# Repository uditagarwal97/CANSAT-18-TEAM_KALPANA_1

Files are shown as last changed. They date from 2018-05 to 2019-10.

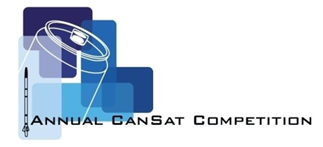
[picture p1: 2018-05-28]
GCS_VIEW/images/acc.PNG

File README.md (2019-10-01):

View this project on [CADLAB.io](https://cadlab.io/project/1174). 

# CANSAT-18-TEAM_KALPANA_1
This Repository contains all the code developed during CANSAT'18 compitition by Team Kalpana-1(ID 2426).

## About the CanSat compition
This annual competition is open to teams from universities and colleges. Teams were asked to design and build a space-type system, following the approved competition guide, and then compete against each at the end of two semesters to determine the winners. For more information please head over to: 
[Compitition website](http://www.cansatcompetition.com/index.html)

## Our problem statement
The 2018 mission simulates a space probe (CanSat) entering a planetary atmosphere. The probe shall carry a single large hen's egg. The egg must survive all portions of flight. The operation sequence shall be:

1. The probe is launched to an altitude of 670 meters to 725 meters and then deployed from the rocket. Orientation of deployment is not controlled and is most definitely violent.

2. Once deployed, the probe shall open an aero-braking heat shield. The descent rate shall be kept at 10 to 30 meters/sec. The aero-braking probe must maintain a stable orientation with the heat shield facing the direction of descent during descent. Tumbling is not allowed. Active control surfaces or other non pyrotechnic mechanisms can be used to maintain orientation.

3. At an altitude of 300 meters, the probe shall release the aero-braking heat shield and simultaneously deploy a parachute to reduce the descent rate of 5 meters/sec.

4. The probe shall land leaving the egg intact.

The probe shall include sensors for tracking altitude using air pressure, external temperature, battery voltage and GPS position. A compartment shall be included to hold a large hen's egg. The egg will simulate a delicate instrument. 

Visit the following link for detailed info of our approach: [Link](http://uditagarwal.in/wiki/index.php/CANSAT18)

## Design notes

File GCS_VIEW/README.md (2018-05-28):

# GCSView
This folder contains GUI files developed for Ground Control Station to view incoming data packets in real time. 
Software has been developed in Python using PyQt4 and matplotlib.

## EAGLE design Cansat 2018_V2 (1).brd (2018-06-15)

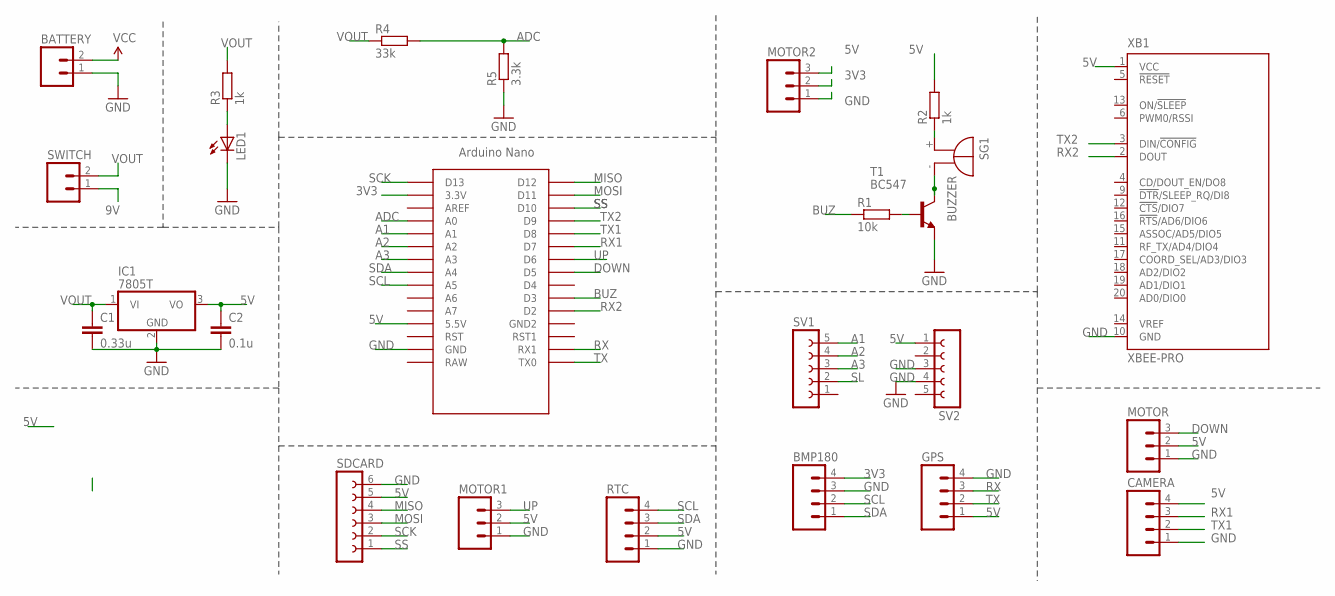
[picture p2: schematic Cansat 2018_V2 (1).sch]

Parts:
BATTERY: M02; 02P
BMP180: M04; 04P
C1: 0.33u; C0805
C2: 0.1u; C0805
CAMERA: M04; 04P
GPS: M04; 04P
IC1: 7805T; TO220H
LED1: LED3MM
MOTOR, MOTOR1, MOTOR2: M03; 03P
R1: 10k; 0207/7
R2: 1k; 0207/7
R3: 1k; 0204/7
R4: 33k; 0207/7
R5: 3.3k; 0207/10
RTC: M04; 04P
SDCARD: FE06-1; FE06
SG1: BUZZER; F/TMB
SV1, SV2: FE05-1
SWITCH: M02; 02P
T1: BC547; TO92
U$1: NANO
XB1: XBEE-PRO

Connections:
3V3: BMP180.4, MOTOR2.2, U$1.3.3V
5V: C2.1, CAMERA.4, GPS.1, IC1.3 (VO), MOTOR.2, MOTOR1.2, MOTOR2.3, R2.2, RTC.2, SDCARD.5, SV2.1, U$1.5V (5.5V), XB1.1 (VCC)
9V: BATTERY.2, SWITCH.1
A1: SV1.5, U$1.A1
A2: SV1.4, U$1.A2
A3: SV1.3, U$1.A3
ADC: R4.2, R5.2, U$1.A0
BUZ: R1.1, U$1.D3
DOWN: MOTOR.3, U$1.D5
GND: BATTERY.1, BMP180.3, C1.2, C2.2, CAMERA.1, GPS.4, IC1.2 (GND), LED1.K (C), MOTOR.1, MOTOR1.1, MOTOR2.1, R5.1, RTC.1, SDCARD.6, SV2.3, SV2.4, T1.1 (E), U$1.GND, XB1.10 (GND)
MISO: SDCARD.4, U$1.D12
MOSI: SDCARD.3, U$1.D11
unnamed: R1.2, T1.2 (B)
unnamed: SG1.-, T1.3 (C)
unnamed: R2.1, SG1.+
unnamed: LED1.A, R3.1
RX: GPS.3, U$1.RX1
RX1: CAMERA.3, U$1.D7
RX2: U$1.D2, XB1.2 (DOUT)
SCK: SDCARD.2, U$1.D13
SCL: BMP180.2, RTC.4, U$1.A5
SDA: BMP180.1, RTC.3, U$1.A4
SL: SV1.2
SS: SDCARD.1, U$1.D10
TX: GPS.2, U$1.TX0
TX1: CAMERA.2, U$1.D8
TX2: U$1.D9, XB1.3 (DIN/!CONFIG)
UP: MOTOR1.3, U$1.D6
VOUT: C1.1, IC1.1 (VI), R3.2, R4.1, SWITCH.2

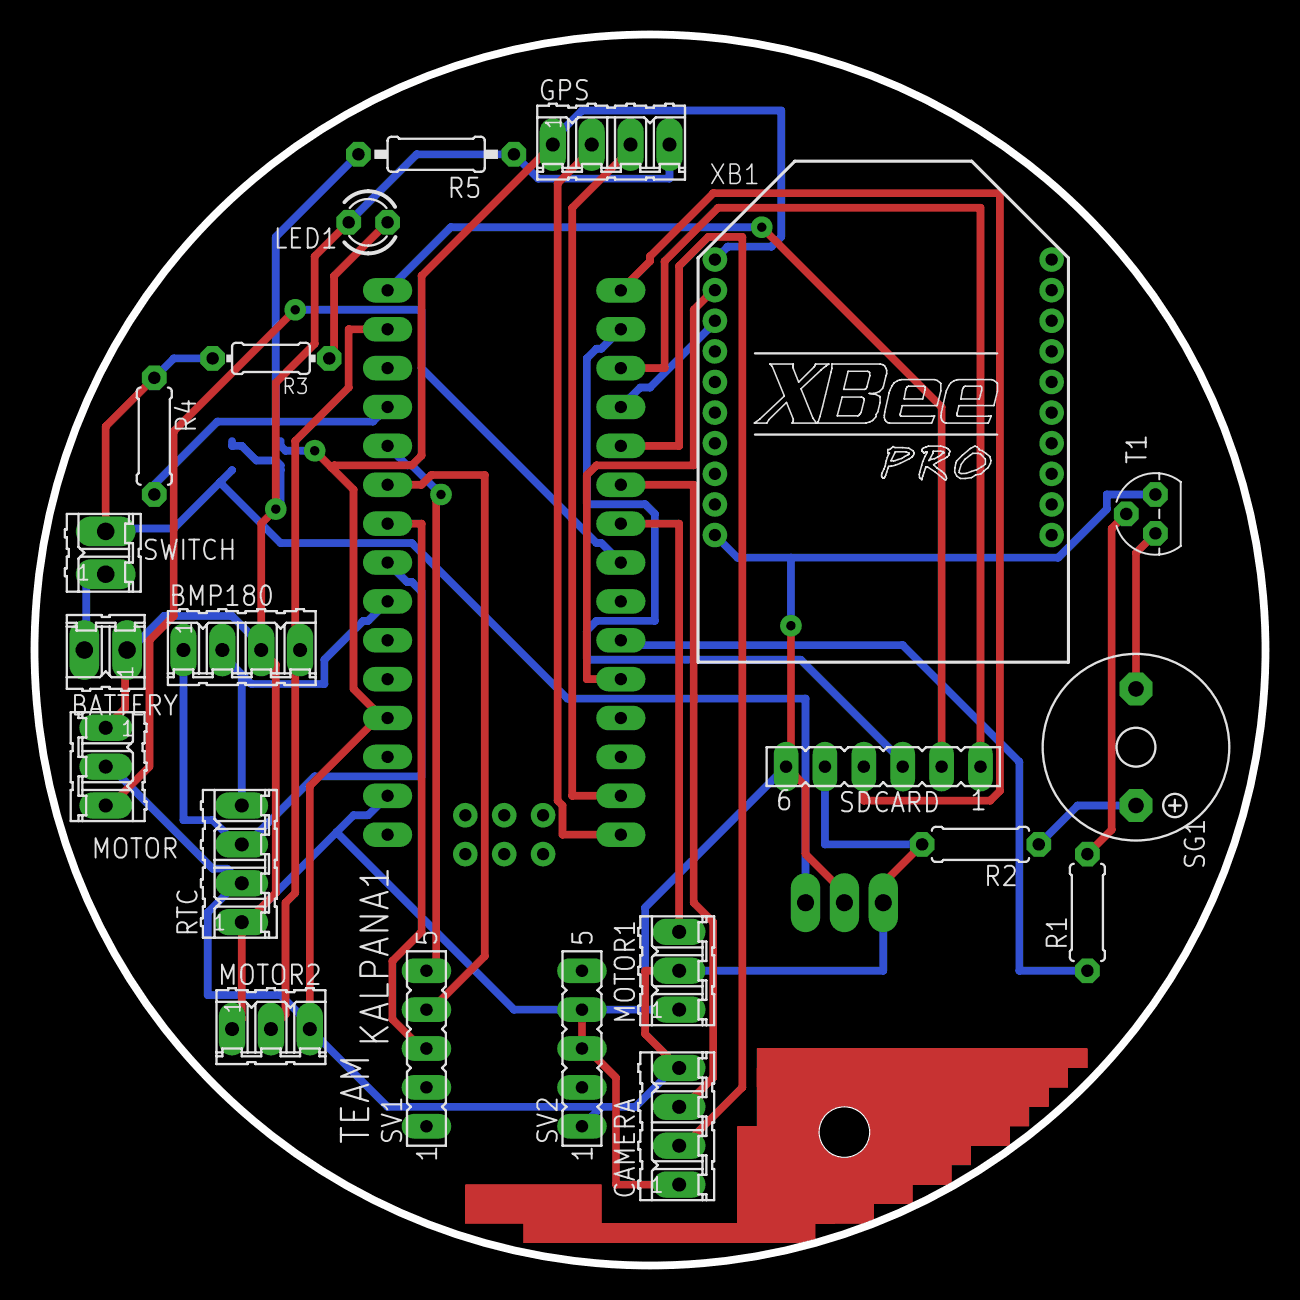
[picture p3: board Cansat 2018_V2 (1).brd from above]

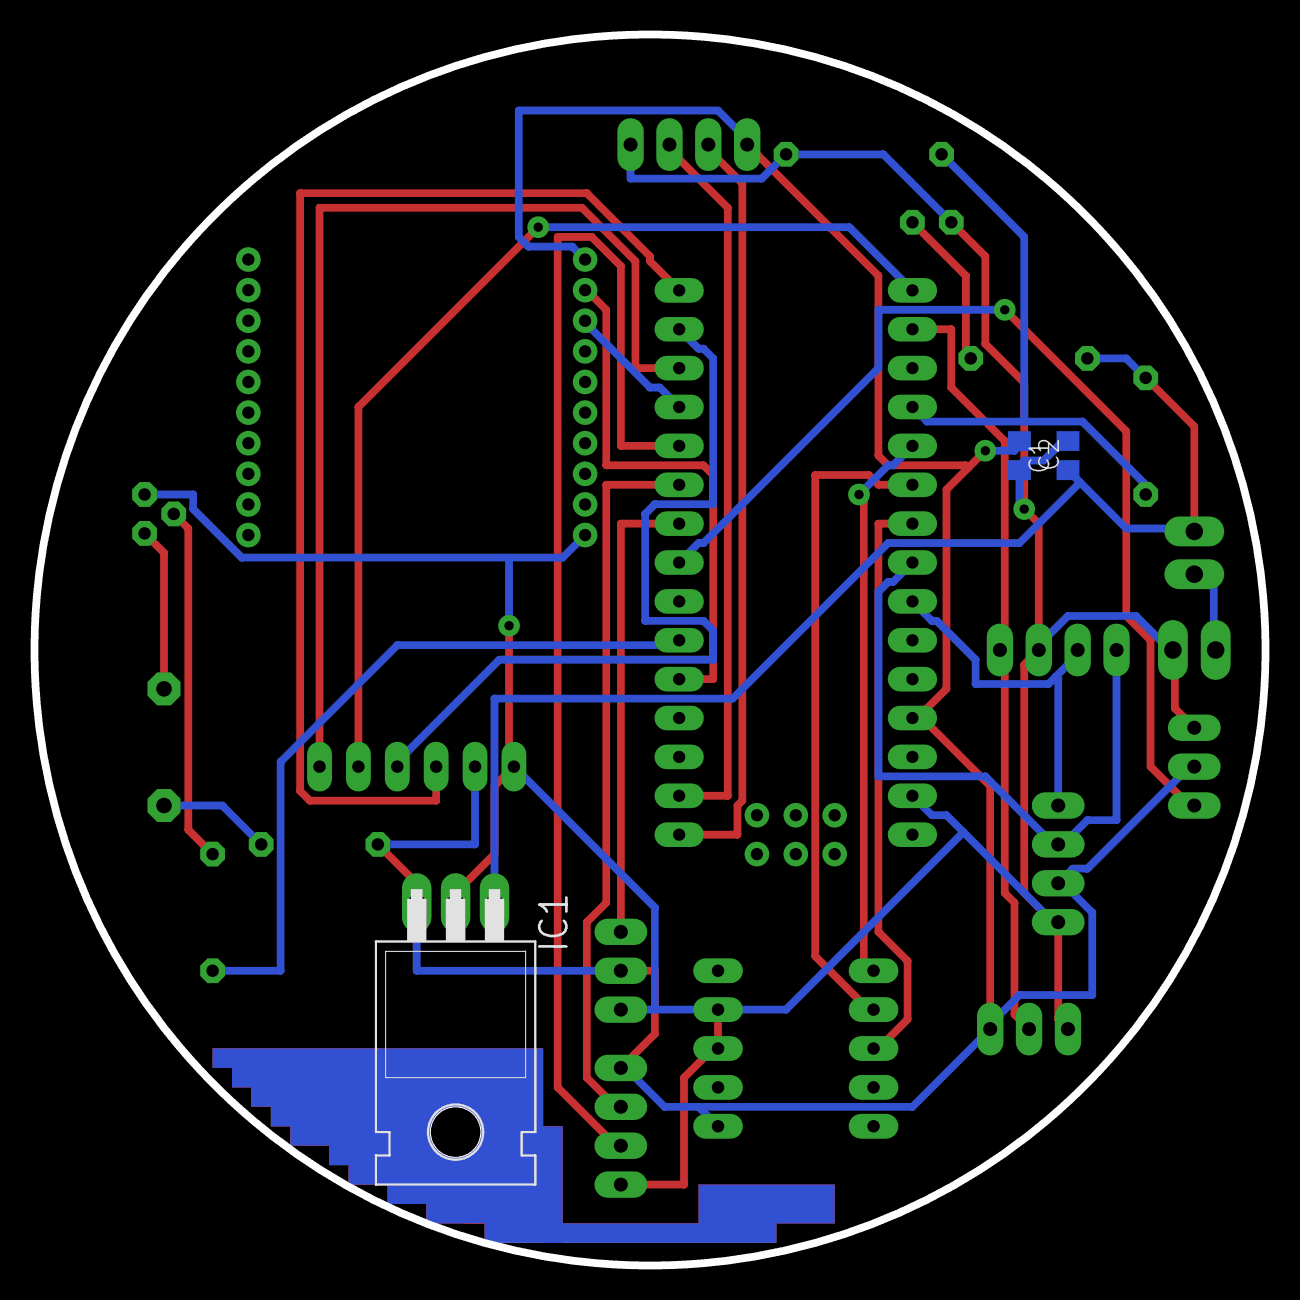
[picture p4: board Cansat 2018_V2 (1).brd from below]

Board: 2 copper layers, 80.4 x 80.4 mm, 25 parts (3 on the bottom side), 28 nets.

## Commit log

2018-05-28 Added eagle CAD design files
    [Cansat 2018_V2.brd, Cansat 2018_V2.sch]
2018-06-15 Updated latest design files
    [Cansat 2018_V2 .brd, Cansat 2018_V2 .sch]
2018-06-15 Resolved merge conflicts
    [Cansat 2018_V2 (1).brd, Cansat 2018_V2 (1).sch, Cansat 2018_V2.brd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]

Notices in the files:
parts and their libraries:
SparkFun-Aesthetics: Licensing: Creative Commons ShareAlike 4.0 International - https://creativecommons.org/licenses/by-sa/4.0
